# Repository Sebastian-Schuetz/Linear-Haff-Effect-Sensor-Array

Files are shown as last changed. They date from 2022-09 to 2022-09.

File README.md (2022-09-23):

# Linear Haff Effect Sensor Array
The files for a simple linear Hall Effect Sensor Array, like the one shown below.
For more infos visit: [https://schuetzbuilds.de](https://schuetzbuilds.de/building-a-linear-hall-effect-sensor-array)

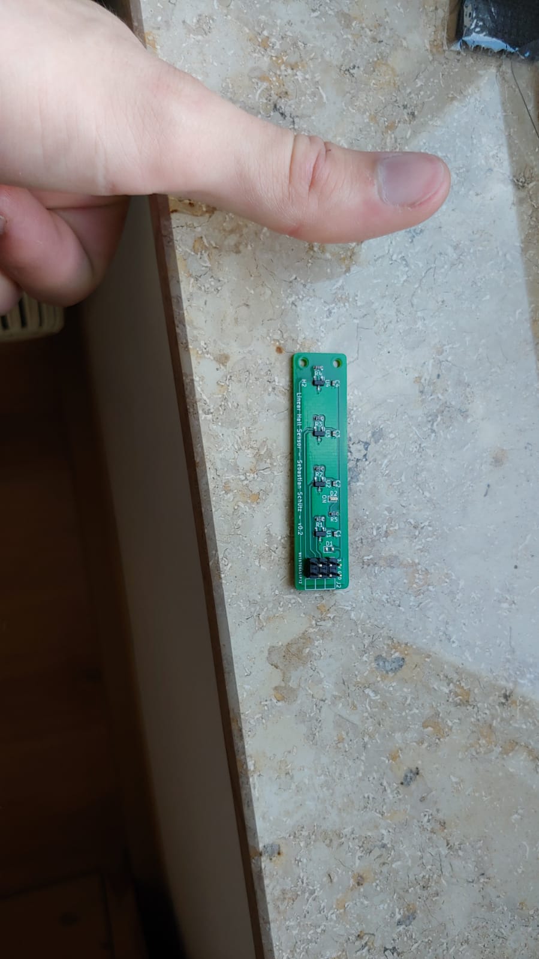
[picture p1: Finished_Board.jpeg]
Finished PCV


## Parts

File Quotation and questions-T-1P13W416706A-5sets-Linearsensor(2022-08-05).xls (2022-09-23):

PCBWay Bom Quotation, Product No.:T-1P13W416706A
Item # | *Designator | *Qty | Manufacturer | *Mfg Part # | *Package/Footprint | *Unit Price(5 sets) | *Total | *Delivery Time | *Actual Purchase Mfg Part # | *PCBWay Note | Customer Reply | PCBWay Update
1 | R2,R4,R1,R3 | 4 | YAGEO | 4,7 k | R_0603_1608Metric | $0.008 | $0.160 |  | RC0603FR-074K7L |  | YES
2 | D1 | 1 | SMC DIODE SOLUTION | DIODE | D_0603_1608Metric |  |  |  | 1655-S1KTR-ND | Please provide exact part number or component URL. | Added the: 1655-S1KTR-N
3 | R5 | 1 | YAGEO | 220 | R_0603_1608Metric | $0.032 | $0.160 |  | RC0603FR-07220RL |  | YES
4 | U3,U4,U2,U1 | 4 | TI | DRV5057A2QDBZT | SOT-23 | $1.971 | $39.420 | 7-10 Workdays | DRV5057A2QDBZT | Only 234pcs total in stock, please confirm ASAP. | YES
5 | C3,C1,C2,C4 | 4 | YAGEO | 10 µF | C_0402_1005Metric | $0.070 | $1.400 |  | CC0402MRX5R6BB106 |  | YES
6 | H2,H1 | 2 |  | MountingHole | MountingHole_2.1mm |  |  |  |  | [DNP不要贴]; | Just mounting holes, were necessary in KiCAD to be specified as components
7 | J2 | 1 | Ckmtw | Conn_02x03_Odd_Even | PinHeader_2x03_P2.54mm_Horizontal | $0.100 | $0.500 |  | B-2100S06P-B110 | Male pin header，2*3pin 2.54mm，made in China，please confirm. | YES
8 | D2 | 1 | LITEON | LED | LED_0603_1608Metric | $0.238 | $1.190 |  | LTST-C191KRKT | Color: GREEN | YES
 |  |  |  |  |  | All Total | $42.830

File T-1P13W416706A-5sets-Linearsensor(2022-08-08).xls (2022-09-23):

PCBWay Bom Quotation, Product No.:T-1P13W416706A
Item # | *Designator | *Qty | Manufacturer | *Mfg Part # | *Package/Footprint | *Unit Price(5 sets) | *Total | *Delivery Time | *Actual Purchase Mfg Part # | *PCBWay Note | Customer Reply | PCBWay Update
1 | R2,R4,R1,R3 | 4 | YAGEO | 4,7 k | R_0603_1608Metric | $0.008 | $0.000 |  | RC0603FR-074K7L
2 | D1 | 1 | SMC Diode Solutions | DIODE | D_0603_1608Metric | $0.488 | $0.000 | 7-10 Workdays | S1K | Brand: onsemi
3 | R5 | 1 | YAGEO | 220 | R_0603_1608Metric | $0.032 | $0.000 |  | RC0603FR-07220RL
4 | U3,U4,U2,U1 | 4 | TI | DRV5057A2QDBZT | SOT-23 | $1.971 | $0.000 | 7-10 Workdays |  | Only 234pcs total in stock, please confirm ASAP.
5 | C3,C1,C2,C4 | 4 | YAGEO | 10 µF | C_0402_1005Metric | $0.070 | $0.000 |  | CC0402MRX5R6BB106
6 | H2,H1 | 2 |  | MountingHole | MountingHole_2.1mm |  |  |  |  | [DNP不要贴];
7 | J2 | 1 | Ckmtw | Conn_02x03_Odd_Even | PinHeader_2x03_P2.54mm_Horizontal | $0.100 | $0.000 |  | B-2100S06P-B110 | Male pin header，2*3pin 2.54mm，made in China，please confirm.
8 | D2 | 1 | LITEON | LED | LED_0603_1608Metric | $0.238 | $0.000 |  | LTST-C191KRKT | Color: RED
 |  |  |  |  |  | All Total | $0.000

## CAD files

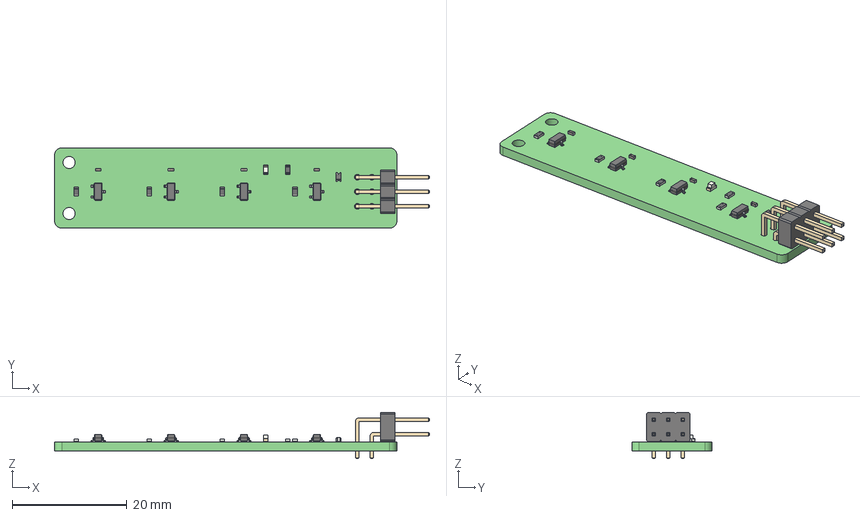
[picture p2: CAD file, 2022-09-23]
Linearsensor.step
65.4 x 14.0 x 8.08 mm
Linearsensor PCB

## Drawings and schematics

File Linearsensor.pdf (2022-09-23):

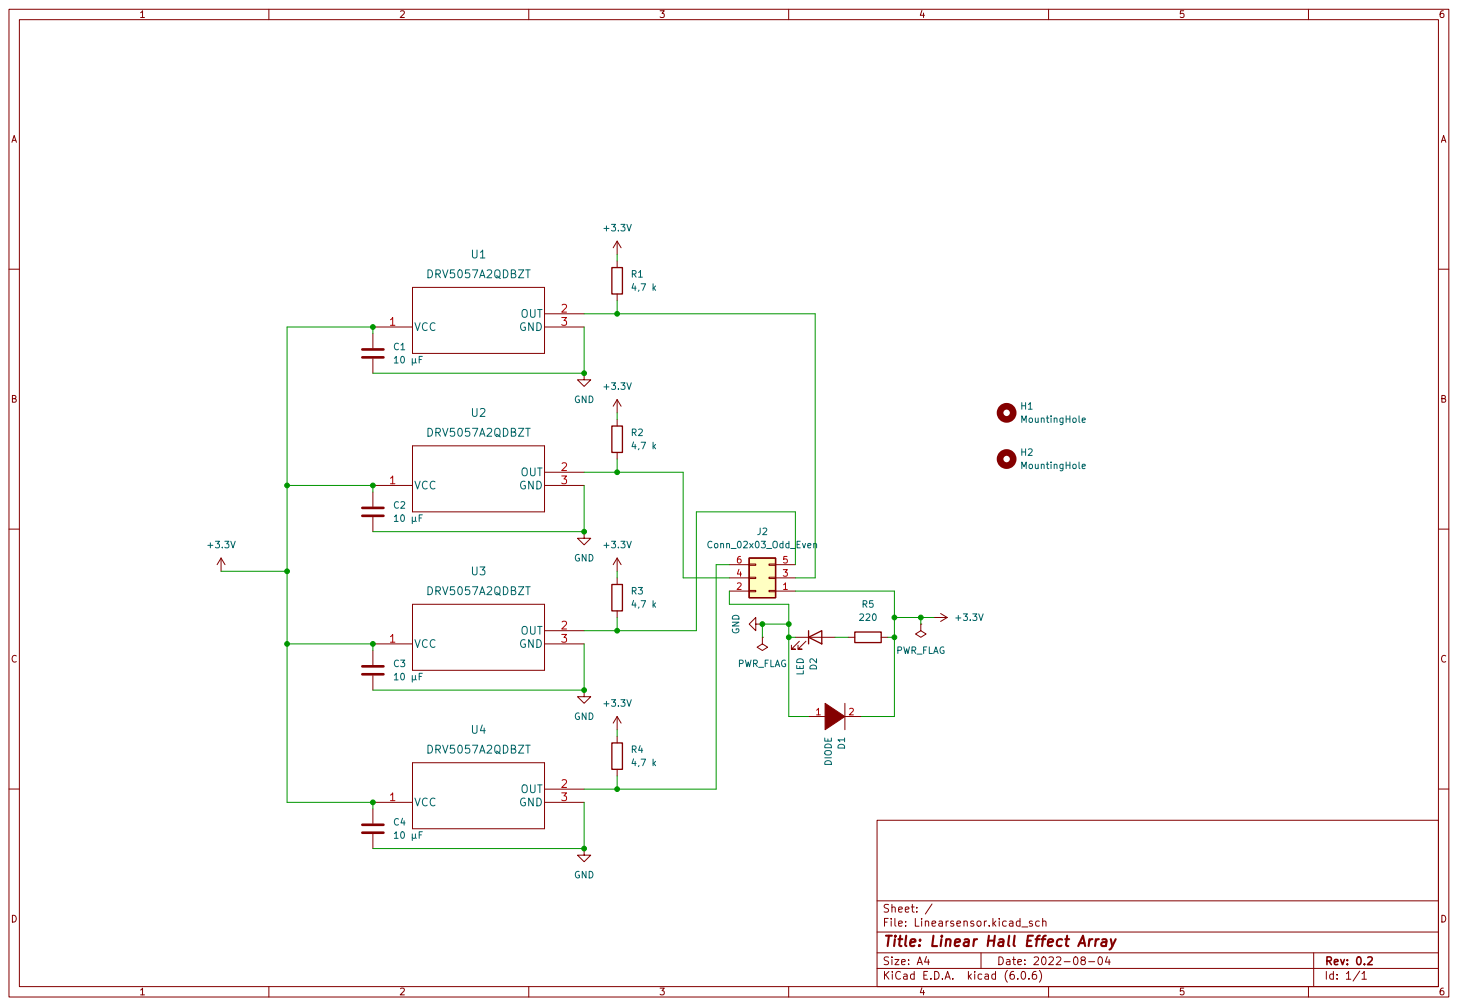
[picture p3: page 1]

Id: 1/1 Title: Linear Hall Effect Array

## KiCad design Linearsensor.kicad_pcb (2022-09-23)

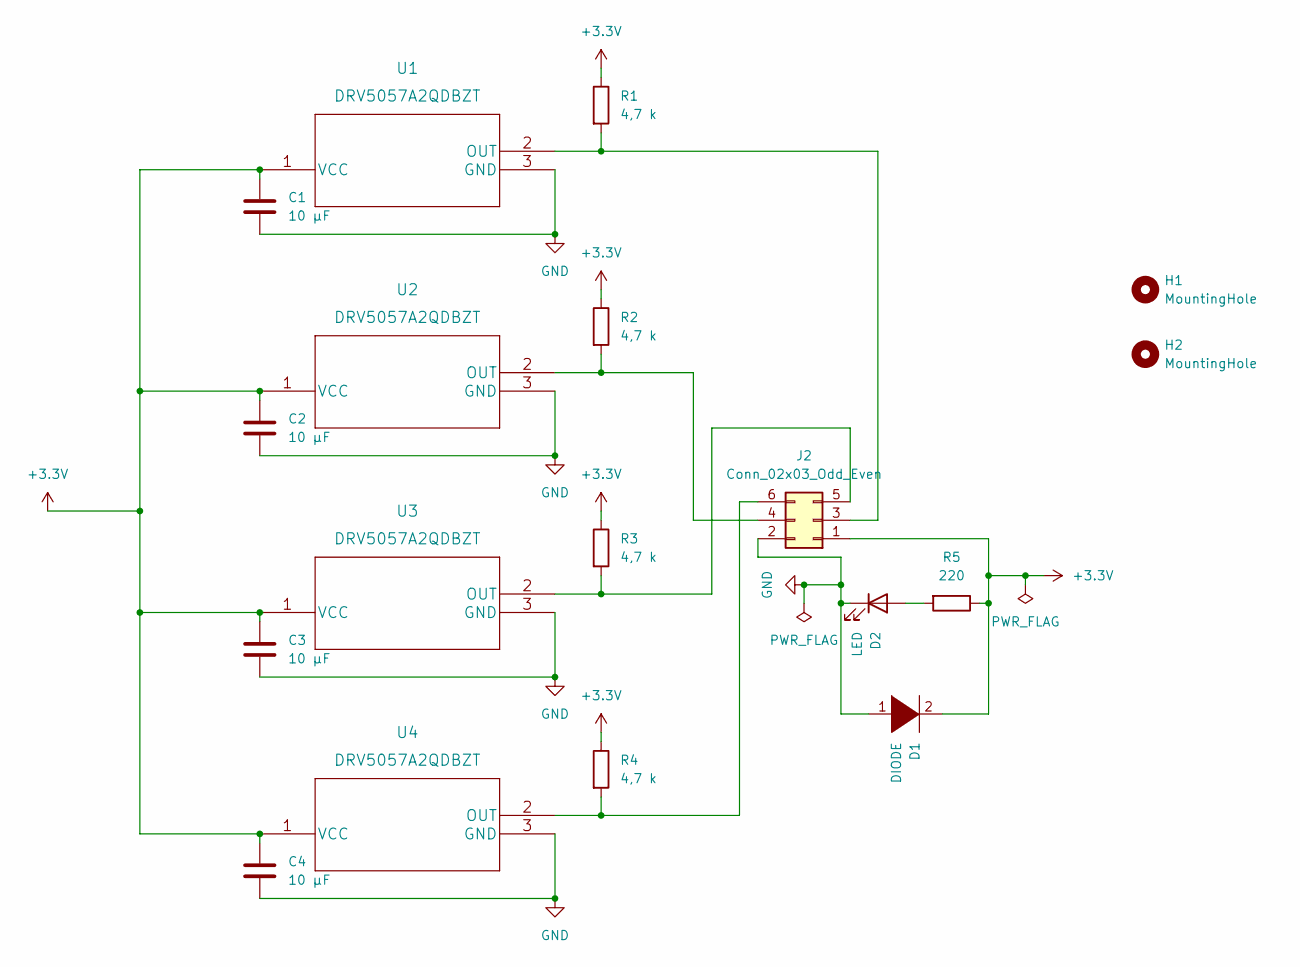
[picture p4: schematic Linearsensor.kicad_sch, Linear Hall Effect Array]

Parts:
C1, C2, C3, C4: 10 µF; C_0402_1005Metric
D1: DIODE; D_0603_1608Metric
D2: LED; LED_0603_1608Metric
H1, H2: MountingHole; MountingHole_2.1mm
J2: Conn_02x03_Odd_Even; PinHeader_2x03_P2.54mm_Horizontal
R1, R2, R3, R4: 4,7 k; R_0603_1608Metric
R5: 220; R_0603_1608Metric
U1, U2, U3, U4: DRV5057A2QDBZT; SOT-23

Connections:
+3.3V: C1.1, C2.1, C3.1, C4.1, D1.2 (A), J2.1, R1.1, R2.1, R3.1, R4.1, R5.1, U1.1 (VCC), U2.1 (VCC), U3.1 (VCC), U4.1 (VCC)
GND: C1.2, C2.2, C3.2, C4.2, D1.1 (K), D2.1 (K), J2.2, U1.3 (GND), U2.3 (GND), U3.3 (GND), U4.3 (GND)
unnamed: D2.2 (A), R5.2
unnamed: J2.3, R1.2, U1.2 (OUT)
unnamed: J2.4, R2.2, U2.2 (OUT)
unnamed: J2.5, R3.2, U3.2 (OUT)
unnamed: J2.6, R4.2, U4.2 (OUT)

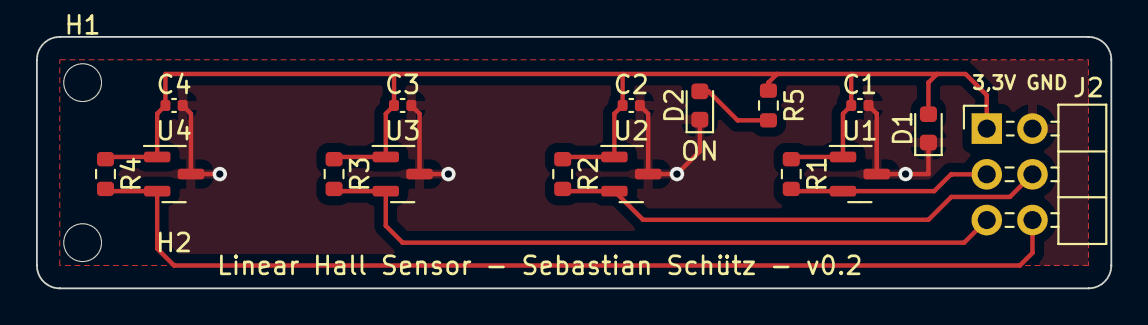
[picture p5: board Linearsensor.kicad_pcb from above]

Board: 2 copper layers, 59.7 x 14.0 mm, 18 parts (0 on the bottom side), 7 nets.
